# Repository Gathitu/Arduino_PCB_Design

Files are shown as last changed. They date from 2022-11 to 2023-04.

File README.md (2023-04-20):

A pdf containing the Printed Circuit Board's (PCB) Design Schematic:
[Schematic_PDF](/Arduino_PCB_Design/Schematic_PDF/Arduino_PCB_Design.pdf)

**Snips of the PCB's views:**

Side View

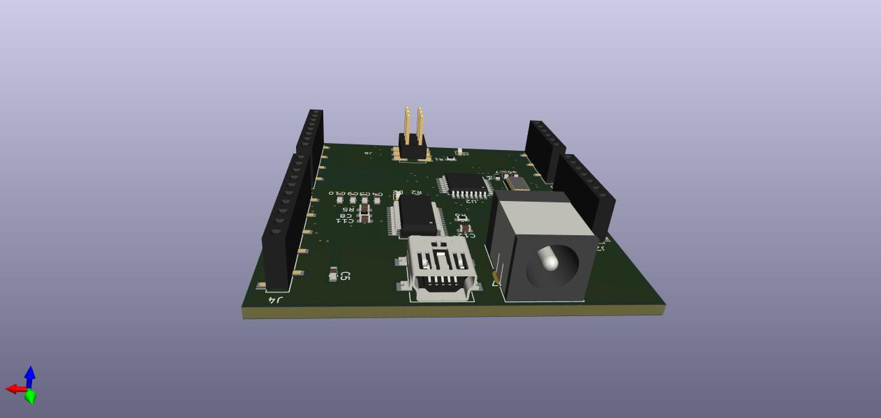
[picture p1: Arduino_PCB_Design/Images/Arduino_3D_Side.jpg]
Side View


Top View

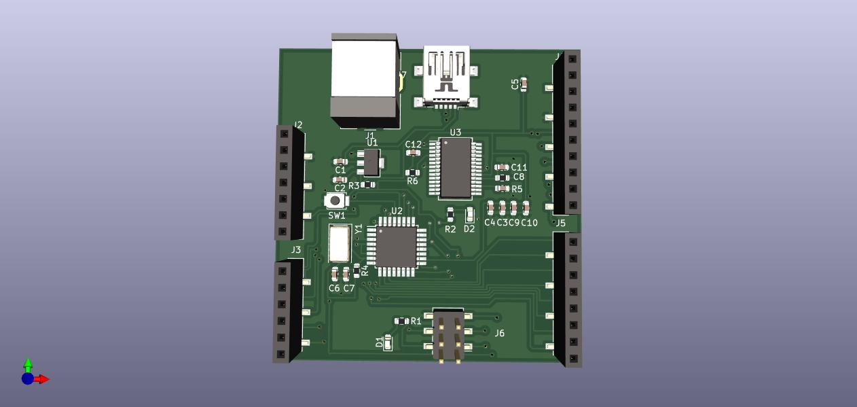
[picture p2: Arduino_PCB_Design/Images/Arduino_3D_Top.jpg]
Top View


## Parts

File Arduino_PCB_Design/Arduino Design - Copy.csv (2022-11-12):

Item | Qty | Reference(s) | Value | LibPart | Footprint | Manufacturing Part Number(MPN) | Vendor | Datasheet
1 | 1 | C1 | 10 uF | Device:C | Capacitor_SMD:C_0603_1608Metric | GRM188R6YA106MA73D | LCSC | https://datasheet.lcsc.com/lcsc/2101281737_Murata-Electronics-GRM188R6YA106MA73D_C194427.pdf
2 | 1 | C2 | 100 uF | Device:C | Capacitor_SMD:C_0603_1608Metric | CL32A107MPVNNNE | DIGIKEY | https://media.digikey.com/pdf/Data%20Sheets/Samsung%20PDFs/CL32A107MPVNNNE_Spec.pdf
3 | 7 | C3, C4, C8, C9, C11, C12 | 100 nF | Device:C | Capacitor_SMD:C_0603_1608Metric | 0603B104K100CT | LCSC | https://datasheet.lcsc.com/lcsc/1912111437_Walsin-Tech-Corp-0603B104K100CT_C424828.pdf
4 | 2 | C6, C7 | 20 pF | Device:C | Capacitor_SMD:C_0603_1608Metric | C0603C200G8HAC7867 | DIGIKEY | https://connect.kemet.com:7667/gateway/IntelliData-ComponentDocumentation/1.0/download/datasheet/C0603C200G8HAC7867
5 | 1 | C10 | 4.7 uF | Device:C | Capacitor_SMD:C_0603_1608Metric | CL10A475KP8NNNC | DIGIKEY | https://media.digikey.com/pdf/Data%20Sheets/Samsung%20PDFs/CL10A475KP8NNNC_Spec.pdf
6 | 2 | D1, D2 | LED | Device:LED | LED_SMD:LED_0603_1608Metric | A-SP192YY3C-A01-4T | LCSC | https://datasheet.lcsc.com/lcsc/2209161630_Amicc-A-SP192YY3C-A01-4T_C5151485.pdf
7 | 1 | J1 | Barrel_Jack | Connector:Barrel_Jack | Connector_BarrelJack:BarrelJack_CUI_PJ-063AH_Horizontal | PJ-614 | LCSC | https://datasheet.lcsc.com/lcsc/2108131730_Korean-Hroparts-Elec-PJ-614_C145801.pdf
8 | 1 | J2 | Conn_01x07_Female | Connector:Conn_01x07_Female | Connector_PinSocket_2.54mm:PinSocket_1x07_P2.54mm_Vertical_SMD_Pin1Left | X6511FRS-07-C85D30 | LCSC | https://datasheet.lcsc.com/lcsc/2208221800_XKB-Connectivity-X6511FRS-07-C85D30_C5142240.pdf
9 | 1 | J3 | Conn_01x06_Female | Connector:Conn_01x06_Female | Connector_PinSocket_2.54mm:PinSocket_1x06_P2.54mm_Vertical_SMD_Pin1Left | X6511FRS-06-C85D30 | LCSC | https://datasheet.lcsc.com/lcsc/2208221800_XKB-Connectivity-X6511FRS-06-C85D30_C5142239.pdf
10 | 1 | J4 | Conn_01x10_Female | Connector:Conn_01x10_Female | Connector_PinSocket_2.54mm:PinSocket_1x10_P2.54mm_Vertical_SMD_Pin1Right | X6511FRS-10-C85D30 | LCSC | https://datasheet.lcsc.com/lcsc/2208221800_XKB-Connectivity-X6511FRS-10-C85D30_C5142243.pdf
11 | 1 | J5 | Conn_01x08_Female | Connector:Conn_01x08_Female | Connector_PinSocket_2.54mm:PinSocket_1x08_P2.54mm_Vertical_SMD_Pin1Right | X6511FRS-08-C85D31 | LCSC | https://datasheet.lcsc.com/lcsc/2208221800_XKB-Connectivity-X6511FRS-08-C85D30_C5142241.pdf
12 | 1 | J6 | ICSP | Connector_Generic:Conn_02x03_Odd_Even | Connector_PinHeader_2.54mm:PinHeader_2x03_P2.54mm_Vertical_SMD | X6521WVS-2x03H-C60D74 | LCSC | https://datasheet.lcsc.com/lcsc/2110111830_XKB-Connectivity-X6521WVS-2x03H-C60D74_C780054.pdf
13 | 1 | J7 | USB_B | Connector:USB_B | Connector_USB:USB_Mini-B_Lumberg_2486_01_Horizontal |  | LCSC | https://www.usb.org/sites/default/files/documents/usb_type-c.zip
14 | 2 | R1, R2 | 300 | Device:R | Resistor_SMD:R_0603_1608Metric | 0603WAF3000T5E | LCSC | https://datasheet.lcsc.com/lcsc/2206010116_UNI-ROYAL-Uniroyal-Elec-0603WAF3000T5E_C23025.pdf
16 | 2 | R3, R4, R6 | 10K | Device:R | Resistor_SMD:R_0603_1608Metric | RC0603JR-0710KL | LCSC | https://datasheet.lcsc.com/lcsc/1811081617_YAGEO-RC0603JR-0710KL_C99198.pdf
17 | 1 | SW1 | Reset_PB | Switch:SW_Push | Button_Switch_SMD:SW_SPST_B3U-1000P | PS-5850A-6PL | LCSC | https://datasheet.lcsc.com/lcsc/2012062037_G-Switch-PS-5850A-6PL_C963201.pdf
18 | 1 | U1 | KIA1117-5.0 | Regulator_Linear:HT75xx-1-SOT89 | Package_TO_SOT_SMD:SOT-89-3 | KIA1117-5.0 | LCSC | https://datasheet.lcsc.com/lcsc/1810271708_KIA-Semicon-Tech-KIA1117-5-0_C116068.pdf
19 | 1 | U2 | ATMEGA328P-AU | MCU_Microchip_ATmega:ATmega328P-A | Package_QFP:TQFP-32_7x7mm_P0.8mm | ATMEGA328P-AU | LCSC | https://datasheet.lcsc.com/lcsc/1809101618_Microchip-Tech-ATMEGA328P-AU_C14877.pdf
20 | 1 | U3 | FT232RL | Interface_USB:FT232RL | Package_SO:SSOP-28_5.3x10.2mm_P0.65mm | FT232RL-REEL | LCSC | https://datasheet.lcsc.com/lcsc/1810311811_FTDI-FT232RL-REEL_C8690.pdf
21 | 1 | Y1 | CSTCE16M0V53-R0 | Device:Crystal | Crystal:Crystal_SMD_0603-2Pin_6.0x3.5mm | CSTCE16M0V53-R0 | LCSC | https://datasheet.lcsc.com/lcsc/1810231814_Murata-Electronics-CSTCE16M0V53-R0_C32180.pdf

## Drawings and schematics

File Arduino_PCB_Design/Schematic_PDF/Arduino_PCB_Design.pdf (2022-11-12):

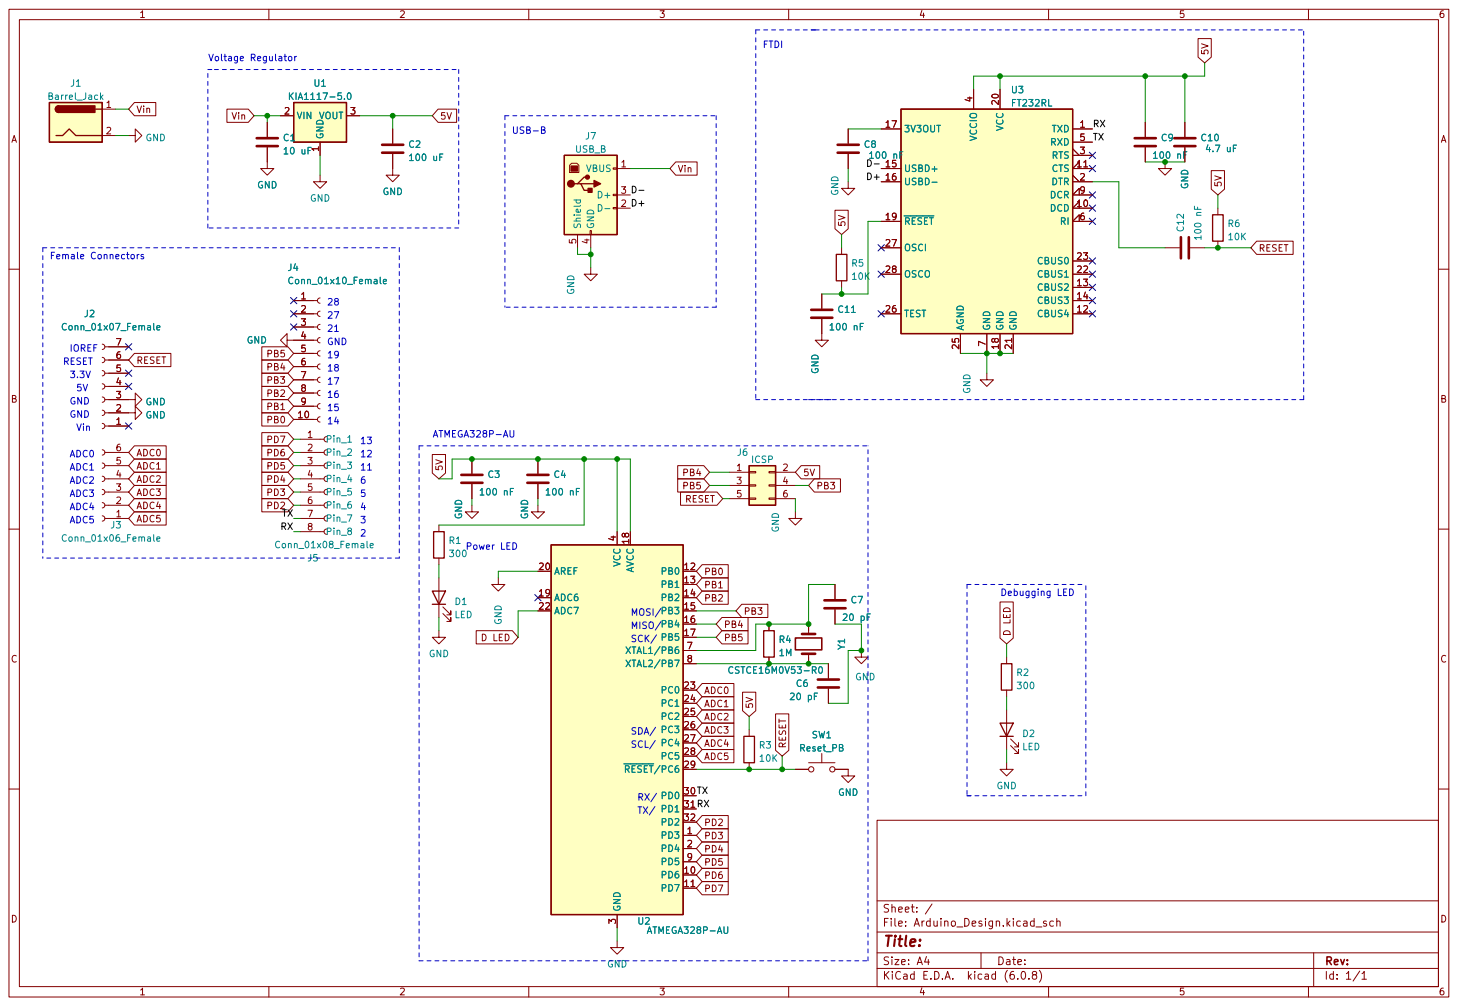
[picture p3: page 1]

Voltage Regulator RESET Vin

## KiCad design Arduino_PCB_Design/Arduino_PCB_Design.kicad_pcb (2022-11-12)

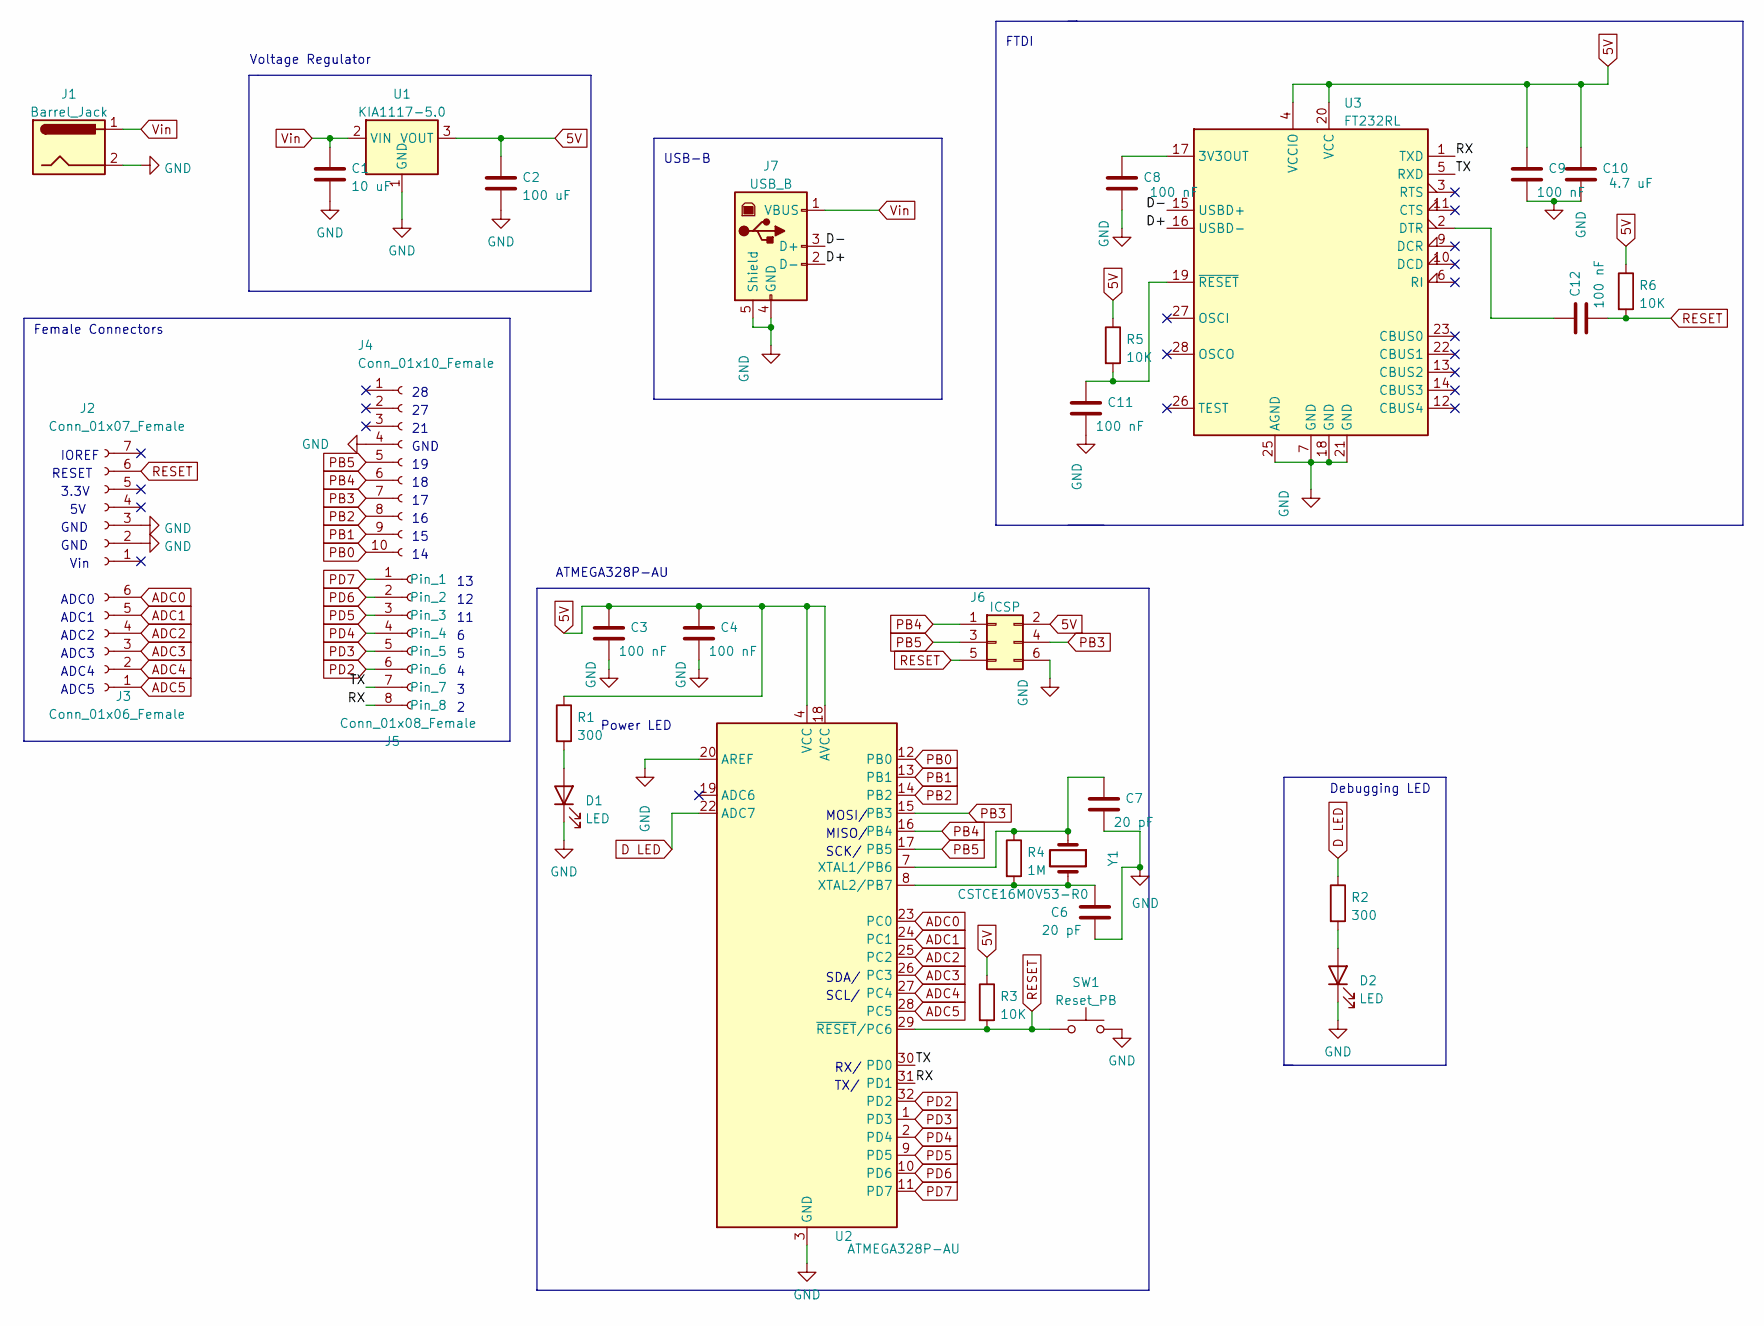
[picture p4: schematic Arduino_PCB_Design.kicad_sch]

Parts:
C1: 10 uF; C_0603_1608Metric
C2: 100 uF; C_0603_1608Metric
C3, C4, C8, C9, C11, C12: 100 nF; C_0603_1608Metric
C6, C7: 20 pF; C_0603_1608Metric
C10: 4.7 uF; C_0603_1608Metric
D1, D2: LED; LED_0603_1608Metric
J1: Barrel_Jack; BarrelJack_CUI_PJ-063AH_Horizontal
J2: Conn_01x07_Female; PinSocket_1x07_P2.54mm_Vertical_SMD_Pin1Left
J3: Conn_01x06_Female; PinSocket_1x06_P2.54mm_Vertical_SMD_Pin1Left
J4: Conn_01x10_Female; PinSocket_1x10_P2.54mm_Vertical_SMD_Pin1Right
J5: Conn_01x08_Female; PinSocket_1x08_P2.54mm_Vertical_SMD_Pin1Right
J6: ICSP; PinHeader_2x03_P2.54mm_Vertical_SMD
J7: USB_B; USB_Mini-B_Lumberg_2486_01_Horizontal
R1, R2: 300; R_0603_1608Metric
R3, R5, R6: 10K; R_0603_1608Metric
R4: 1M; R_0603_1608Metric
SW1: Reset_PB; SW_SPST_B3U-1000P
U1: KIA1117-5.0; SOT-89-3
U2: ATMEGA328P-AU; TQFP-32_7x7mm_P0.8mm
U3: FT232RL; SSOP-28_5.3x10.2mm_P0.65mm
Y1: CSTCE16M0V53-R0; Crystal_SMD_0603-2Pin_6.0x3.5mm

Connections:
5V: C2.1, C3.1, C4.1, C9.1, C10.1, J6.2, R1.1, R3.1, R5.1, R6.1, U1.3 (VOUT), U2.4 (VCC), U2.6 (VCC), U2.18 (AVCC), U3.4 (VCCIO), U3.20 (VCC); also elsewhere on the board
/D+: J7.2 (D-), U3.16 (USBD-)
/D-: J7.3 (D+), U3.15 (USBD+)
/RX: J5.8, U2.31 (PD1), U3.1 (TXD)
/TX: J5.7, U2.30 (PD0), U3.5 (RXD)
ADC0: J3.6, U2.23 (PC0)
ADC1: J3.5, U2.24 (PC1)
ADC2: J3.4, U2.25 (PC2)
ADC3: J3.3, U2.26 (PC3)
ADC4: J3.2, U2.27 (PC4)
ADC5: J3.1, U2.28 (PC5)
D LED: R2.1, U2.22 (ADC7)
GND: C1.2, C2.2, C3.2, C4.2, C6.2, C7.2, C8.2, C9.2, C10.2, C11.2, D1.1 (K), D2.1 (K), J1.2, J2.2, J2.3, J4.4, J6.6, J7.4 (GND), J7.5 (Shield), SW1.2, U1.1 (GND), U2.3 (GND), U2.5 (GND), U2.20 (AREF), U2.21 (GND), U3.7 (GND), U3.18 (GND), U3.21 (GND), U3.25 (AGND); also elsewhere on the board
unnamed: C6.1, R4.2, U2.8 (XTAL2/PB7), Y1.2
unnamed: C7.1, R4.1, U2.7 (XTAL1/PB6), Y1.1
unnamed: C8.1, U3.17 (3V3OUT)
unnamed: C11.1, R5.2, U3.19 (~RESET)
unnamed: C12.1, U3.2 (DTR)
unnamed: D1.2 (A), R1.2
unnamed: D2.2 (A), R2.2
PB0: J4.10, U2.12 (PB0)
PB1: J4.9, U2.13 (PB1)
PB2: J4.8, U2.14 (PB2)
PB3: J4.7, J6.4, U2.15 (PB3)
PB4: J4.6, J6.1, U2.16 (PB4)
PB5: J4.5, J6.3, U2.17 (PB5)
PD2: J5.6, U2.32 (PD2)
PD3: J5.5, U2.1 (PD3)
PD4: J5.4, U2.2 (PD4)
PD5: J5.3, U2.9 (PD5)
PD6: J5.2, U2.10 (PD6)
PD7: J5.1, U2.11 (PD7)
RESET: C12.2, J2.6, J6.5, R3.2, R6.2, SW1.1, U2.29 (~RESET/PC6)
Vin: C1.1, J1.1, J7.1 (VBUS), U1.2 (VIN)

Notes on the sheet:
SCL/
ADC5
IOREF
Debugging LED
USB-B
SDA/
FTDI
GND
Female Connectors
Vin
ADC4
Power LED
ADC3
ADC2
Voltage Regulator
ADC1
MISO/
RESET
GND
RX/
ADC0
SCK/
MOSI/
3.3V
TX/
ATMEGA328P-AU

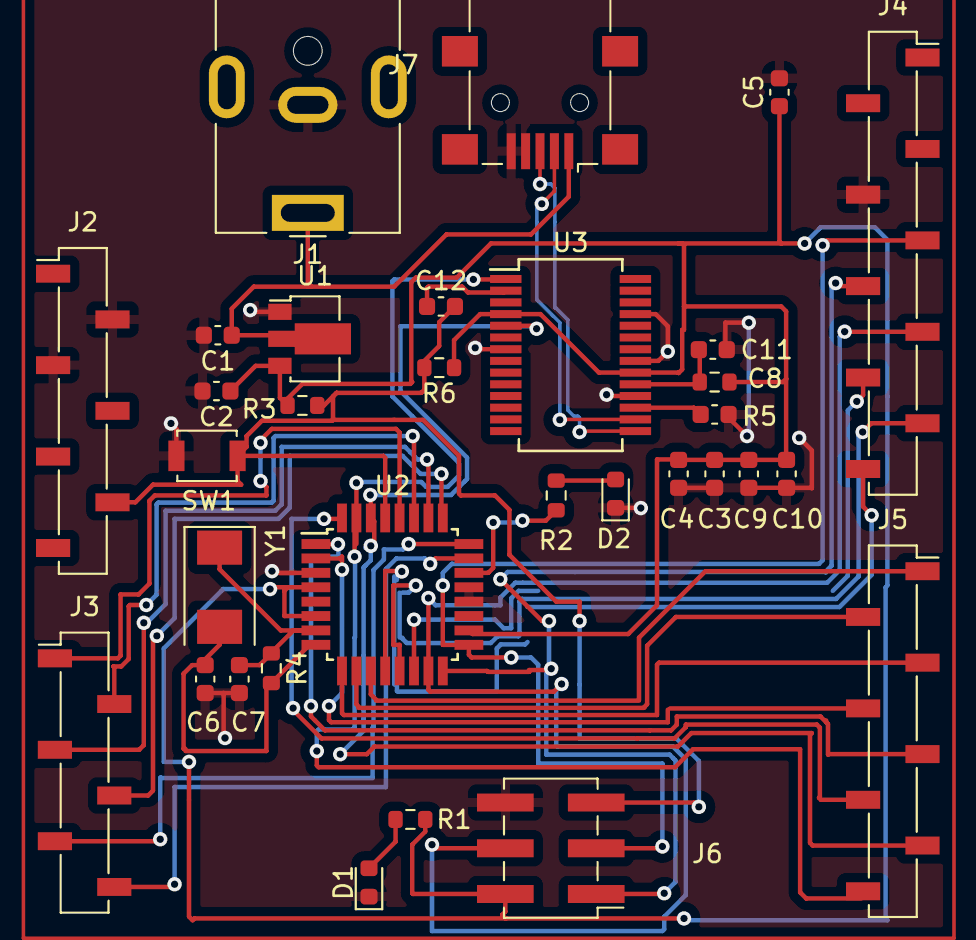
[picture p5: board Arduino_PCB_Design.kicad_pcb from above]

Board: 2 copper layers, 32 parts (0 on the bottom side), 34 nets.

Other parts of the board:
C5: 100 nF; C_0603_1608Metric

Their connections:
5V: C5.1; also elsewhere on the board
GND: C5.2; also elsewhere on the board
